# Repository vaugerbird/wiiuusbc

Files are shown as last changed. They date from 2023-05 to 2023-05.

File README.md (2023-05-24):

# wiiuusbc

A simple mod board for the WiiU gamepad that replaces the stock connector with a USB C port. The CC pins are connected and use 2 56kΩ resistors that allow for 500mA charging.

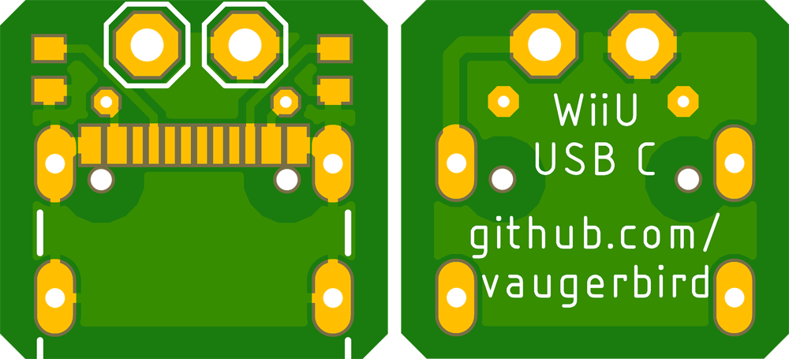
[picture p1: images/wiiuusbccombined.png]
Board Render


## Parts

Only 3 parts are used (other than the board).

* 1x of GCT USB4105-GF-A: [Mouser](https://www.mouser.com/ProductDetail/640-USB4105-GF-A) - [Digikey](https://www.digikey.com/en/products/detail/gct/USB4105-GF-A/11198441)
* 2x of ROHM SFR01MZPF5602: [Mouser]([https://www.mouser.com/ProductDetail/ROHM-Semiconductor/SFR01MZPF5602](https://www.mouser.com/ProductDetail/ROHM-Semiconductor/SFR01MZPF5602?qs=byeeYqUIh0PMHn%2FWHQ30Hw%3D%3D)) - [Digikey](https://www.digikey.com/en/products/detail/rohm-semiconductor/SFR01MZPF5602/16009123)

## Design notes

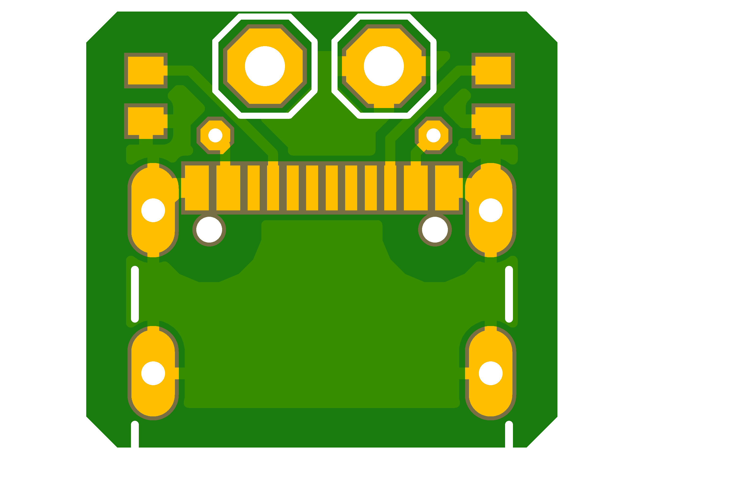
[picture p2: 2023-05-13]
images/wiiuusbctop.png

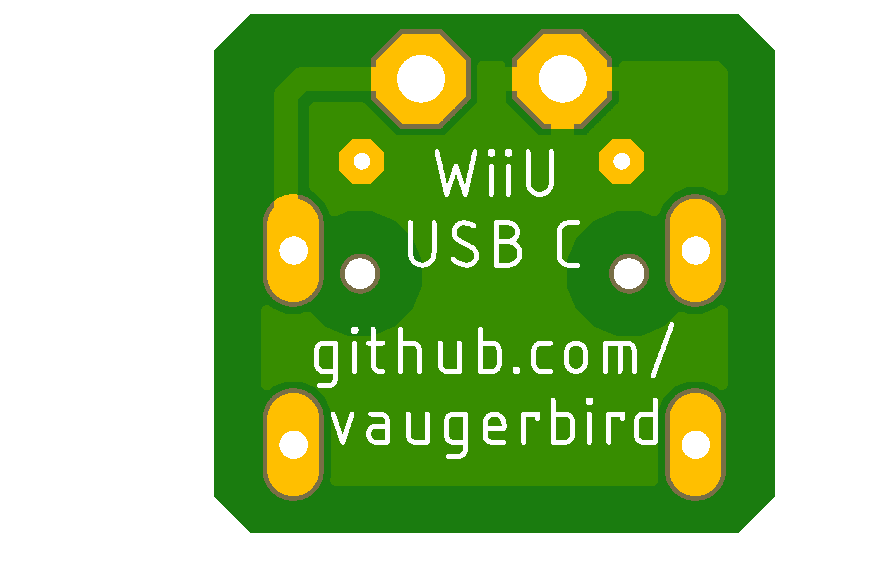
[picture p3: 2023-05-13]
images/wiiuusbcbottom.png

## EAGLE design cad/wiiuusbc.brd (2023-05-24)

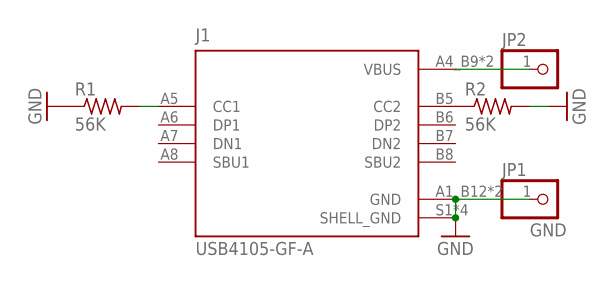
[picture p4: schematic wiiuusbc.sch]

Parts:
J1: USB4105-GF-A; GCT_USB4105-GF-A
JP1, JP2: PINHD-1X1; 1X01
R1, R2: 56K; R0402

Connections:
CC1: J1.A5 (CC1), R1.2
CC2: J1.B5 (CC2), R2.1
GND: J1.A1_B12 (GND), J1.B1_A12 (GND), J1.S1 (SHELL_GND), J1.S2 (SHELL_GND), J1.S3 (SHELL_GND), J1.S4 (SHELL_GND), JP1.1, R1.1, R2.2
VCC: J1.A4_B9 (VBUS), J1.B4_A9 (VBUS), JP2.1

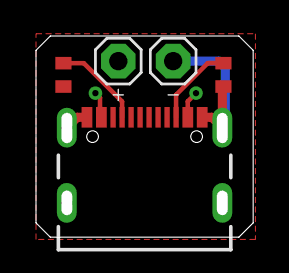
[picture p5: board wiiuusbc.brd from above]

Board: 2 copper layers, 12.1 x 11.2 mm, 5 parts (0 on the bottom side), 4 nets.

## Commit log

2023-05-13 add board files
    [wiiuusbc.brd, wiiuusbc.sch]
2023-05-13 connect CC lines and update readme
    [wiiuusbc.brd, wiiuusbc.sch]
2023-05-13 Add images
    [wiiuusbc.brd]
2023-05-24 Fix mouser resistor link
2023-05-24 Update silkscreen
    [wiiuusbc.brd]
